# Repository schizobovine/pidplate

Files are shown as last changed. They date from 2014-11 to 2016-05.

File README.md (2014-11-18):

pidplate
========

Arduino-ish PID temperature controller for a hotplate based solder reflow-ing thingy.

hardware - Contains the Eagle schematic and board layout
firmware - Arduino sketch & makefile to build code to run it

Bill of materials still TODO, as I haven't really finalized each part, but know
the footprints for each and want to get the board to the fab before I grow old.

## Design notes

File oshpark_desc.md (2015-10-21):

PID temperature controller shield for reading in thermocouple data and using the results to control a SSR. Based on MAX 31855 thermocouple amplifier. Has a [Newport PCC-SMP-K mini thermocouple connector](http://www.newark.com/newport-electronics/pcc-smp-k/thermocouple-connector-type-k/dp/01H0905), JST XH-4 connector to the SSR/PSU assembly, and a header for the [Adafruit 128x32 I2C OLED Display](https://www.adafruit.com/products/931).

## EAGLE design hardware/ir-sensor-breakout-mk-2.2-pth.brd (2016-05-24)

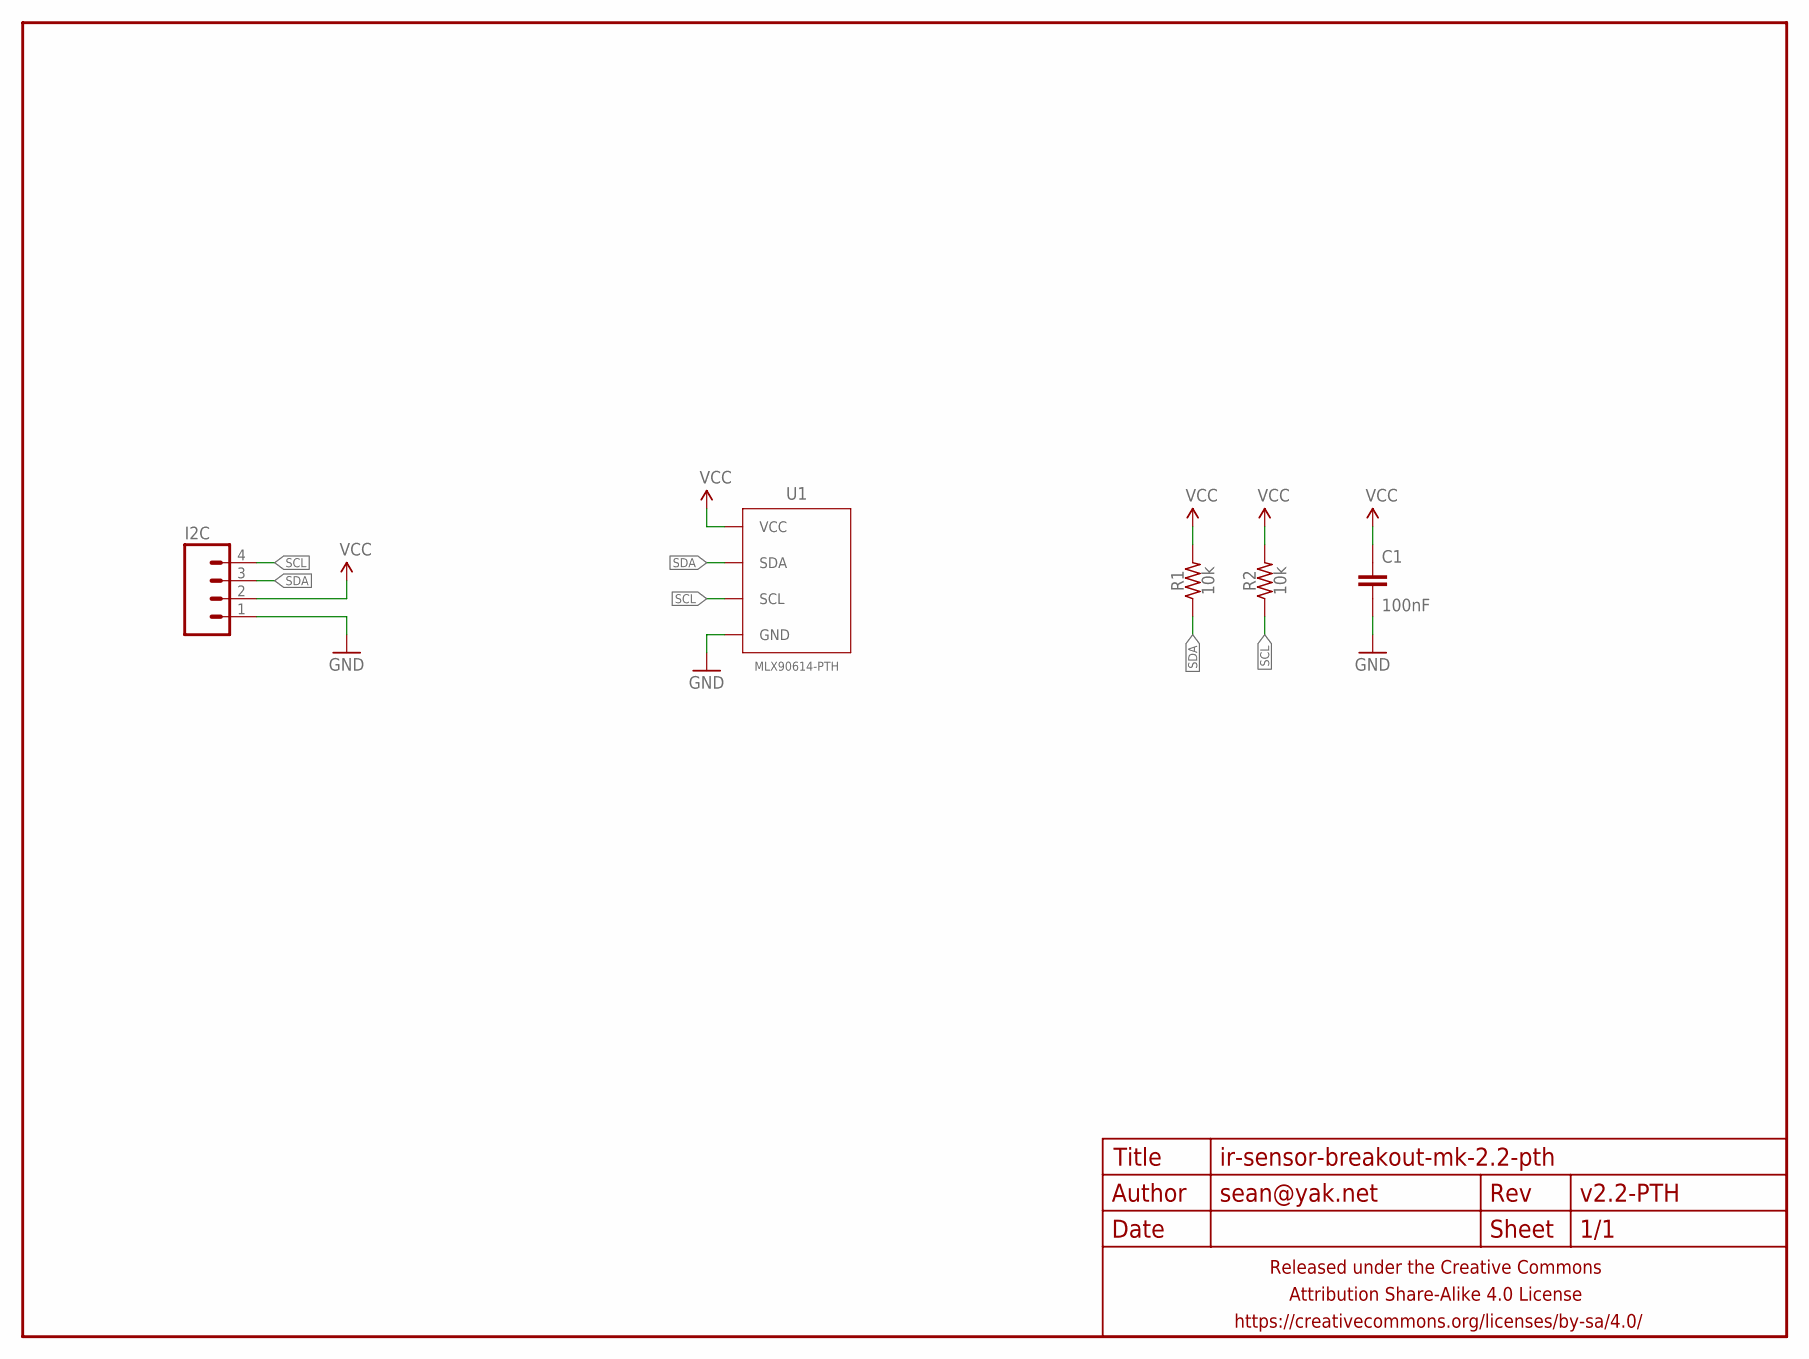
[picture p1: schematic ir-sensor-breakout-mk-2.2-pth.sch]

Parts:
C1: 100nF; C025-024X044
FRAME1: FRAME-LETTERNO_PACKAGE; DUMMY
I2C: M04JST-PTH-VERT; JST-4-PH-VERT-PTH
R1, R2: 10k; RESISTOR-AXIAL-PTH-6.35MM
U1: MLX90614-PTH; TO-39-4

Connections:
GND: C1.2, I2C.1, U1.4 (GND)
SCL: I2C.4, R2.P$1 (1), U1.1 (SCL)
SDA: I2C.3, R1.P$1 (1), U1.2 (SDA)
VCC: C1.1, I2C.2, R1.P$2 (2), R2.P$2 (2), U1.3 (VCC)

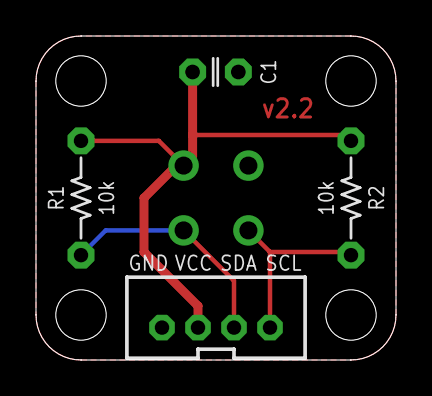
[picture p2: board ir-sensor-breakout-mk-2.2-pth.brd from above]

Board: 2 copper layers, 20.0 x 18.0 mm, 6 parts (1 on the bottom side), 4 nets.

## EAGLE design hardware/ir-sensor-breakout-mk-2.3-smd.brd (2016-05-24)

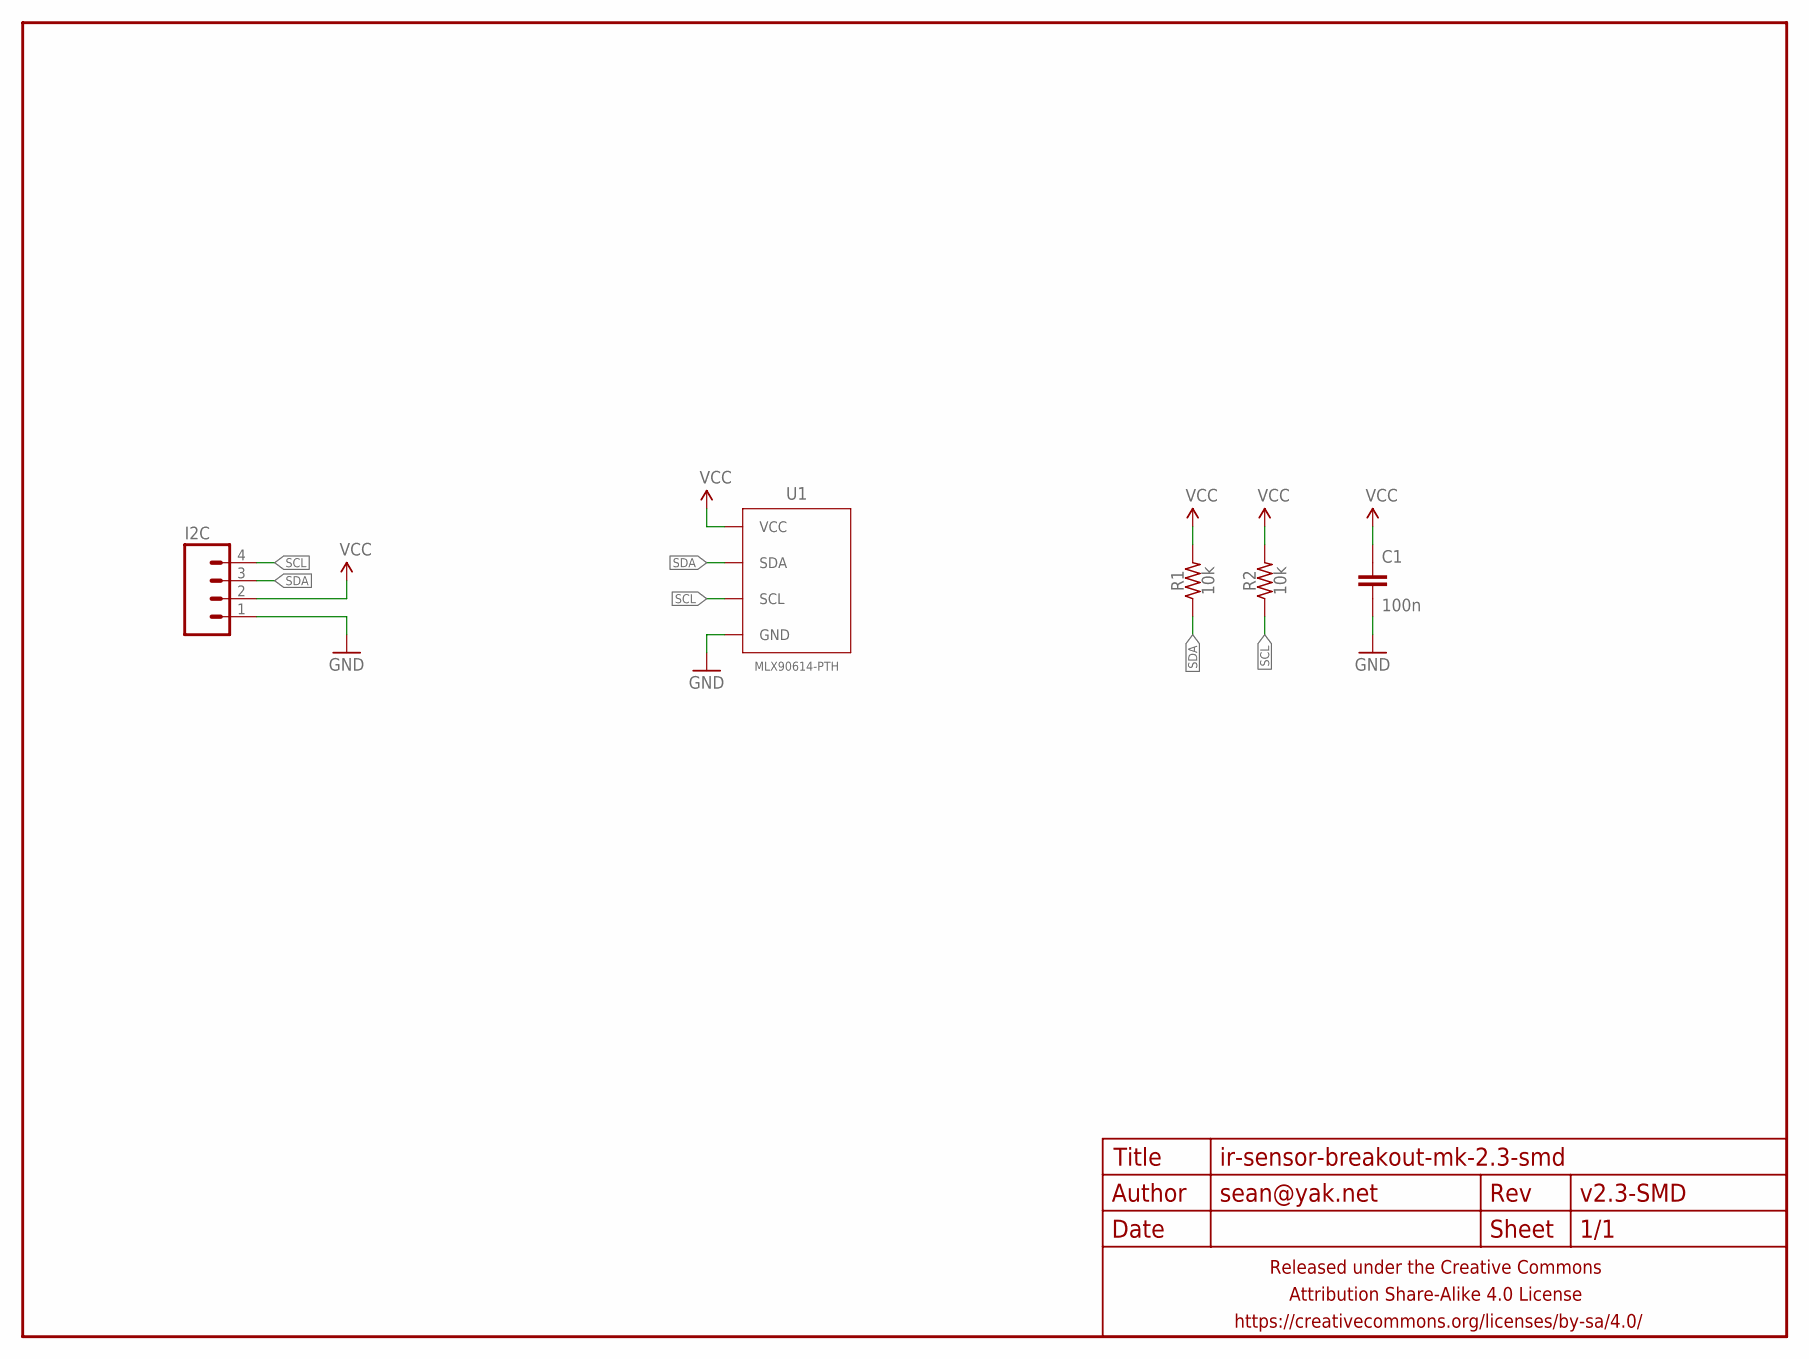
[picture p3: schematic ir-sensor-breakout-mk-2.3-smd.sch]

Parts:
C1: 100n; C0805
FRAME1: FRAME-LETTERNO_PACKAGE; DUMMY
I2C: M04JST-PTH-VERT; JST-4-PH-VERT-PTH
R1, R2: 10k; R0805
U1: MLX90614-PTH; TO-39-4

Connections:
GND: C1.2, I2C.1, U1.4 (GND)
SCL: I2C.4, R2.1, U1.1 (SCL)
SDA: I2C.3, R1.1, U1.2 (SDA)
VCC: C1.1, I2C.2, R1.2, R2.2, U1.3 (VCC)

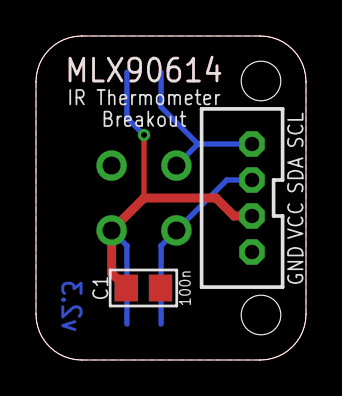
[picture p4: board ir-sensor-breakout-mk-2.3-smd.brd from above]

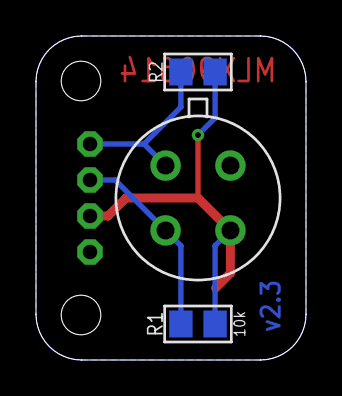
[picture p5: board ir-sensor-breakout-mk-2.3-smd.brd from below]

Board: 2 copper layers, 15.0 x 18.0 mm, 6 parts (3 on the bottom side), 4 nets.

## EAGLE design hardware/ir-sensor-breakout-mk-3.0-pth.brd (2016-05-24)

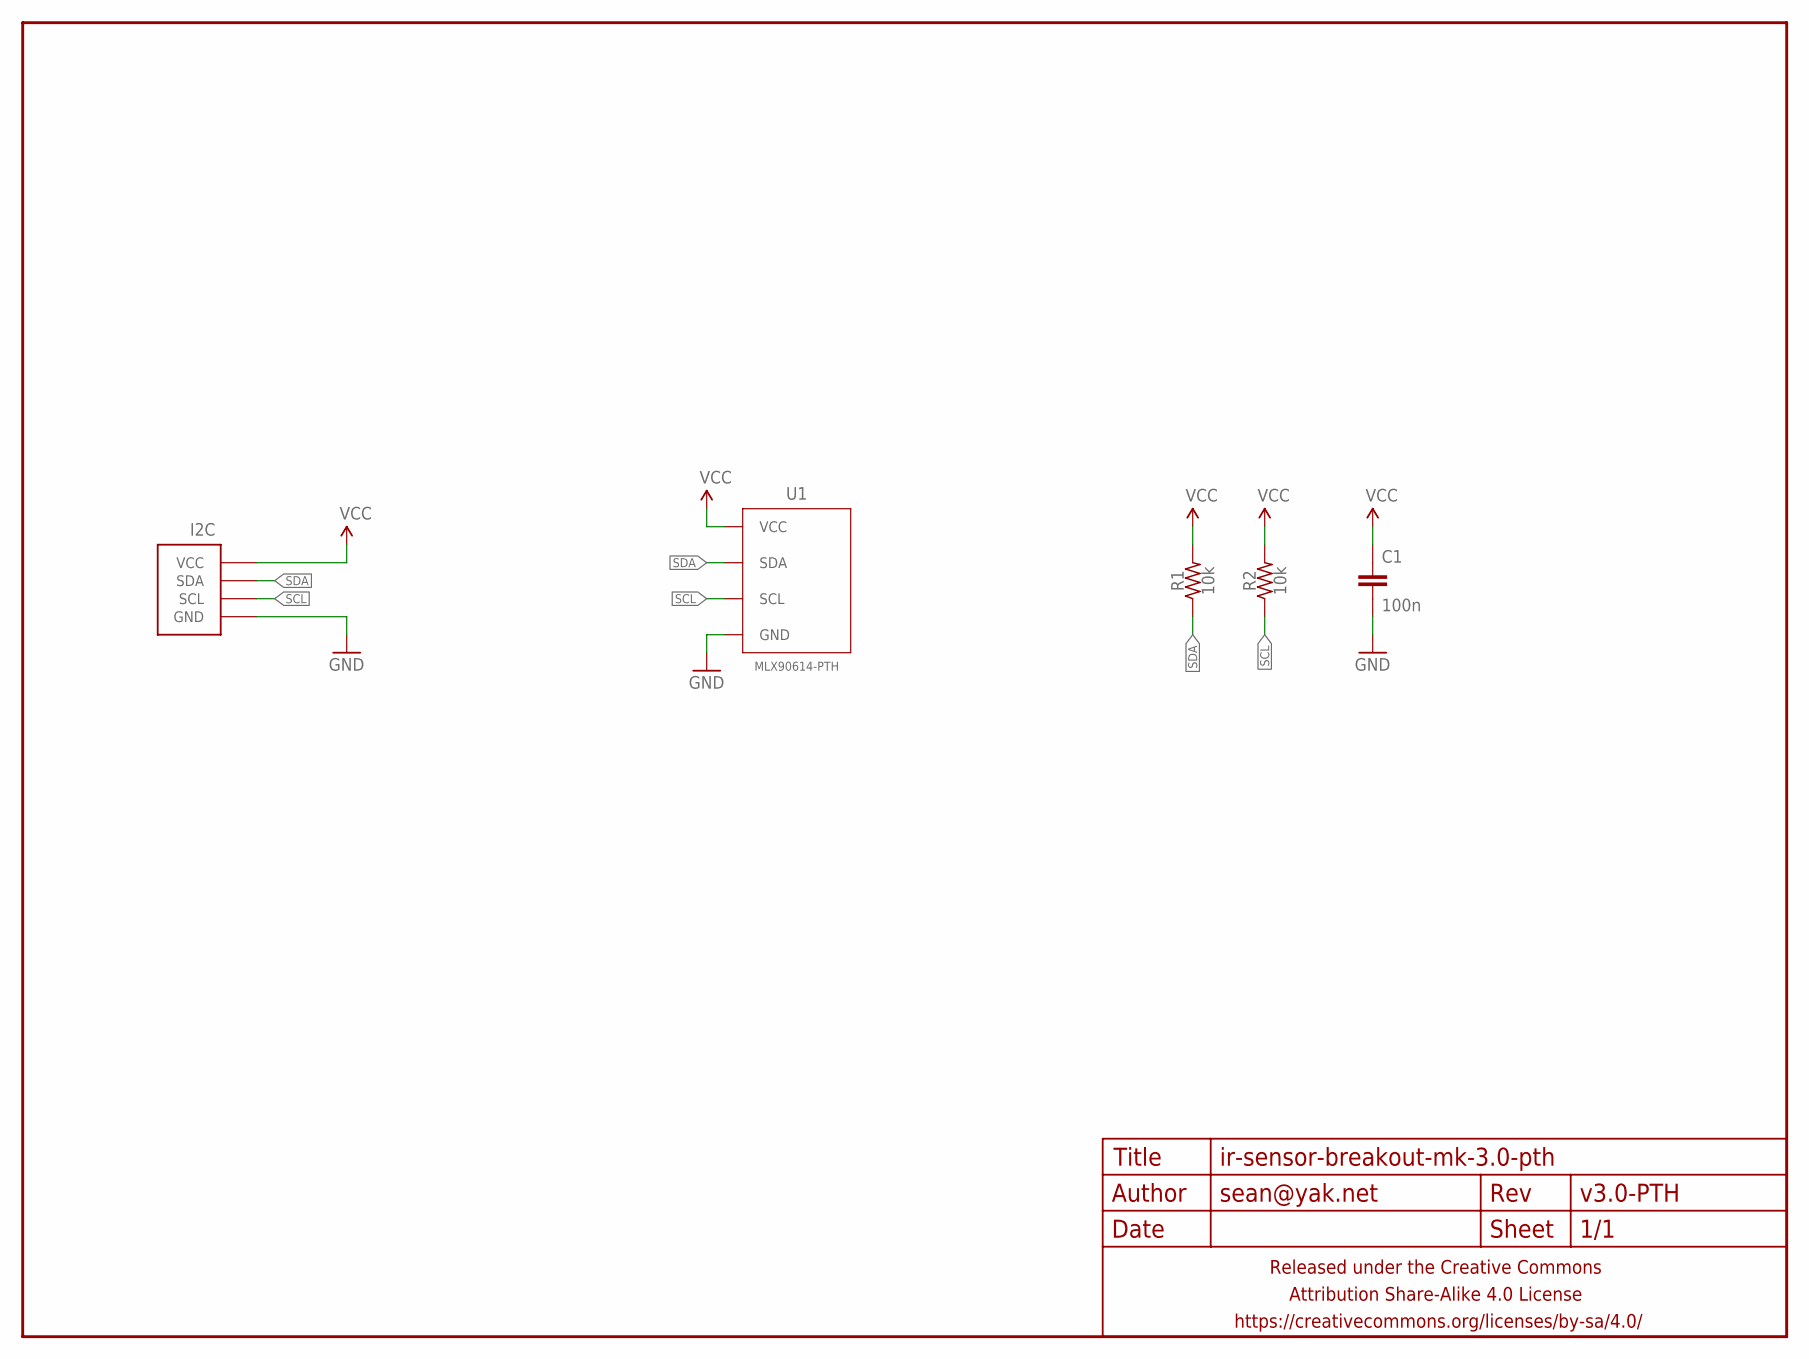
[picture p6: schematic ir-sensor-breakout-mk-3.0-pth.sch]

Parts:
C1: 100n; C025-024X044
FRAME1: FRAME-LETTERNO_PACKAGE; DUMMY
I2C: M04-I2CPTH-0.1IN-CENTERED-FLIPPED; 1X04-PTH-VERT-I2C-CENTERED-FLIPPED
R1, R2: 10k; RESISTOR-AXIAL-PTH-5.08MM
U1: MLX90614-PTH; TO-39-4

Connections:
GND: C1.2, I2C.GND, U1.4 (GND)
SCL: I2C.SCL, R2.P$1 (1), U1.1 (SCL)
SDA: I2C.SDA, R1.P$1 (1), U1.2 (SDA)
VCC: C1.1, I2C.VCC, R1.P$2 (2), R2.P$2 (2), U1.3 (VCC)

Board: 2 copper layers, 6 parts (1 on the bottom side), 4 nets, no tracks yet.

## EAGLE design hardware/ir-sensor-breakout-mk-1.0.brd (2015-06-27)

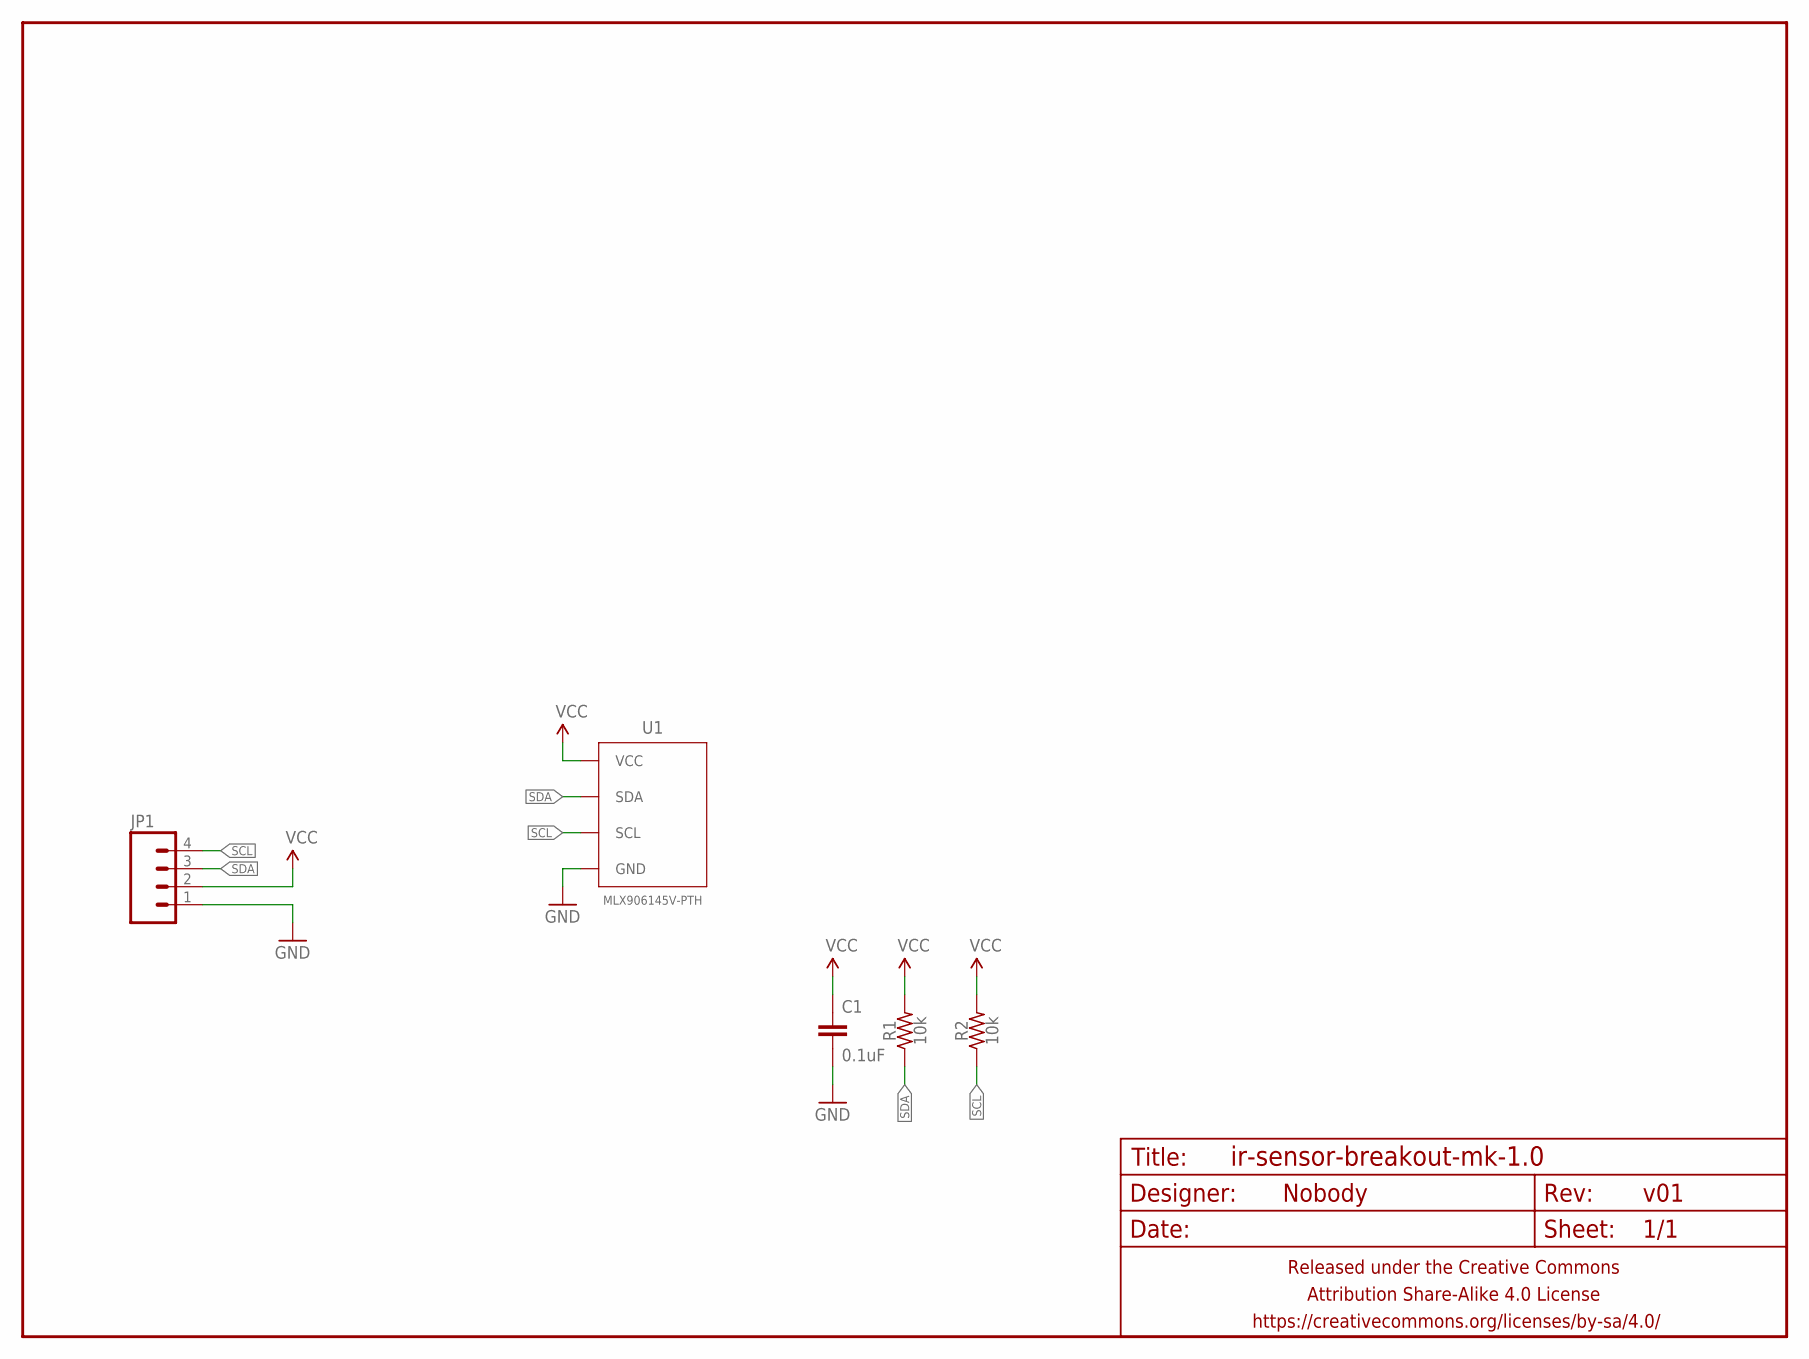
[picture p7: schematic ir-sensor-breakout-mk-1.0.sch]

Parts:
C1: 0.1uF; C025-024X044
FRAME1: FRAME-LETTERNO_PACKAGE; DUMMY
JP1: M04JST-PTH; JST-4-PH-RA-PTH
R1, R2: 10k; RESISTOR-AXIAL-PTH-7.62MM
U1: MLX906145V-PTH; TO-39-4

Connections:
GND: C1.2, JP1.1, U1.4 (GND)
SCL: JP1.4, R2.P$1 (1), U1.1 (SCL)
SDA: JP1.3, R1.P$1 (1), U1.2 (SDA)
VCC: C1.1, JP1.2, R1.P$2 (2), R2.P$2 (2), U1.3 (VCC)

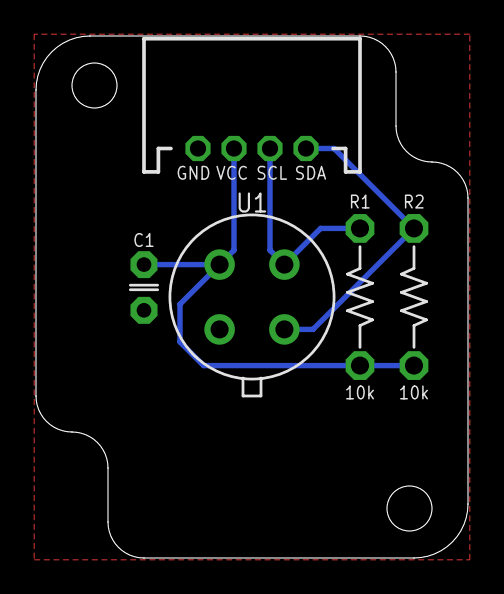
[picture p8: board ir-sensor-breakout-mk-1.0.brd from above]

Board: 2 copper layers, 24.0 x 29.0 mm, 6 parts (0 on the bottom side), 4 nets.

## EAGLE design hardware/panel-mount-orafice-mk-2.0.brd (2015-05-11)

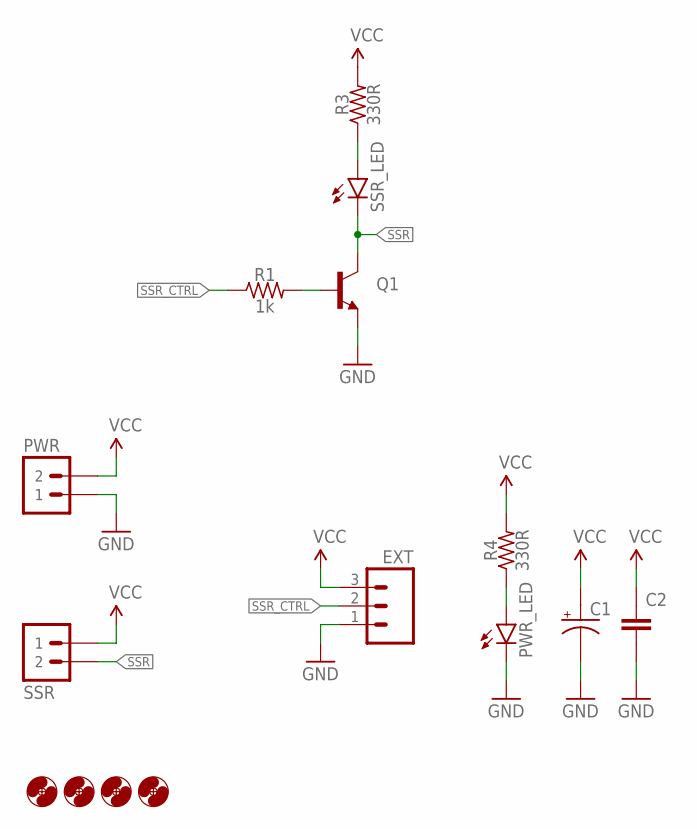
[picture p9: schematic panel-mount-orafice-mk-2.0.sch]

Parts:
C1: CAPACITOR-POLARIZEDE3.5-8; E3,5-8
C2: CAPACITOR-CERAMIC025-024X044; C025-024X044
EXT: M03JST-XH-RA-PTH; JST-3-XH-RA-PTH
H1, H2, H3, H4: HOLE#2; HOLE-#2
PWR: M02JST-PTH-VERT; JST-2-PH-VERT-PTH
PWR_LED: LED3MM
Q1: TRANSISTOR_NPNTO-92-AMMO-EBC; TO-92-AMMO
R1: 1k; RESISTOR-AXIAL-PTH-6.35MM
R3, R4: 330R; RESISTOR-AXIAL-PTH-6.35MM
SSR: M02JST-PTH-VERT; JST-2-PH-VERT-PTH
SSR_LED: LED3MM

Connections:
GND: C1.-, C2.2, EXT.1, PWR.1, PWR_LED.K (C), Q1.1 (E)
unnamed: Q1.2 (B), R1.P$2 (2)
unnamed: R3.P$1 (1), SSR_LED.A
unnamed: PWR_LED.A, R4.P$1 (1)
SSR: Q1.3 (C), SSR.2, SSR_LED.K (C)
SSR_CTRL: EXT.2, R1.P$1 (1)
VCC: C1.+, C2.1, EXT.3, PWR.2, R3.P$2 (2), R4.P$2 (2), SSR.1

Board: 2 copper layers, 15 parts (0 on the bottom side), 7 nets, no tracks yet.

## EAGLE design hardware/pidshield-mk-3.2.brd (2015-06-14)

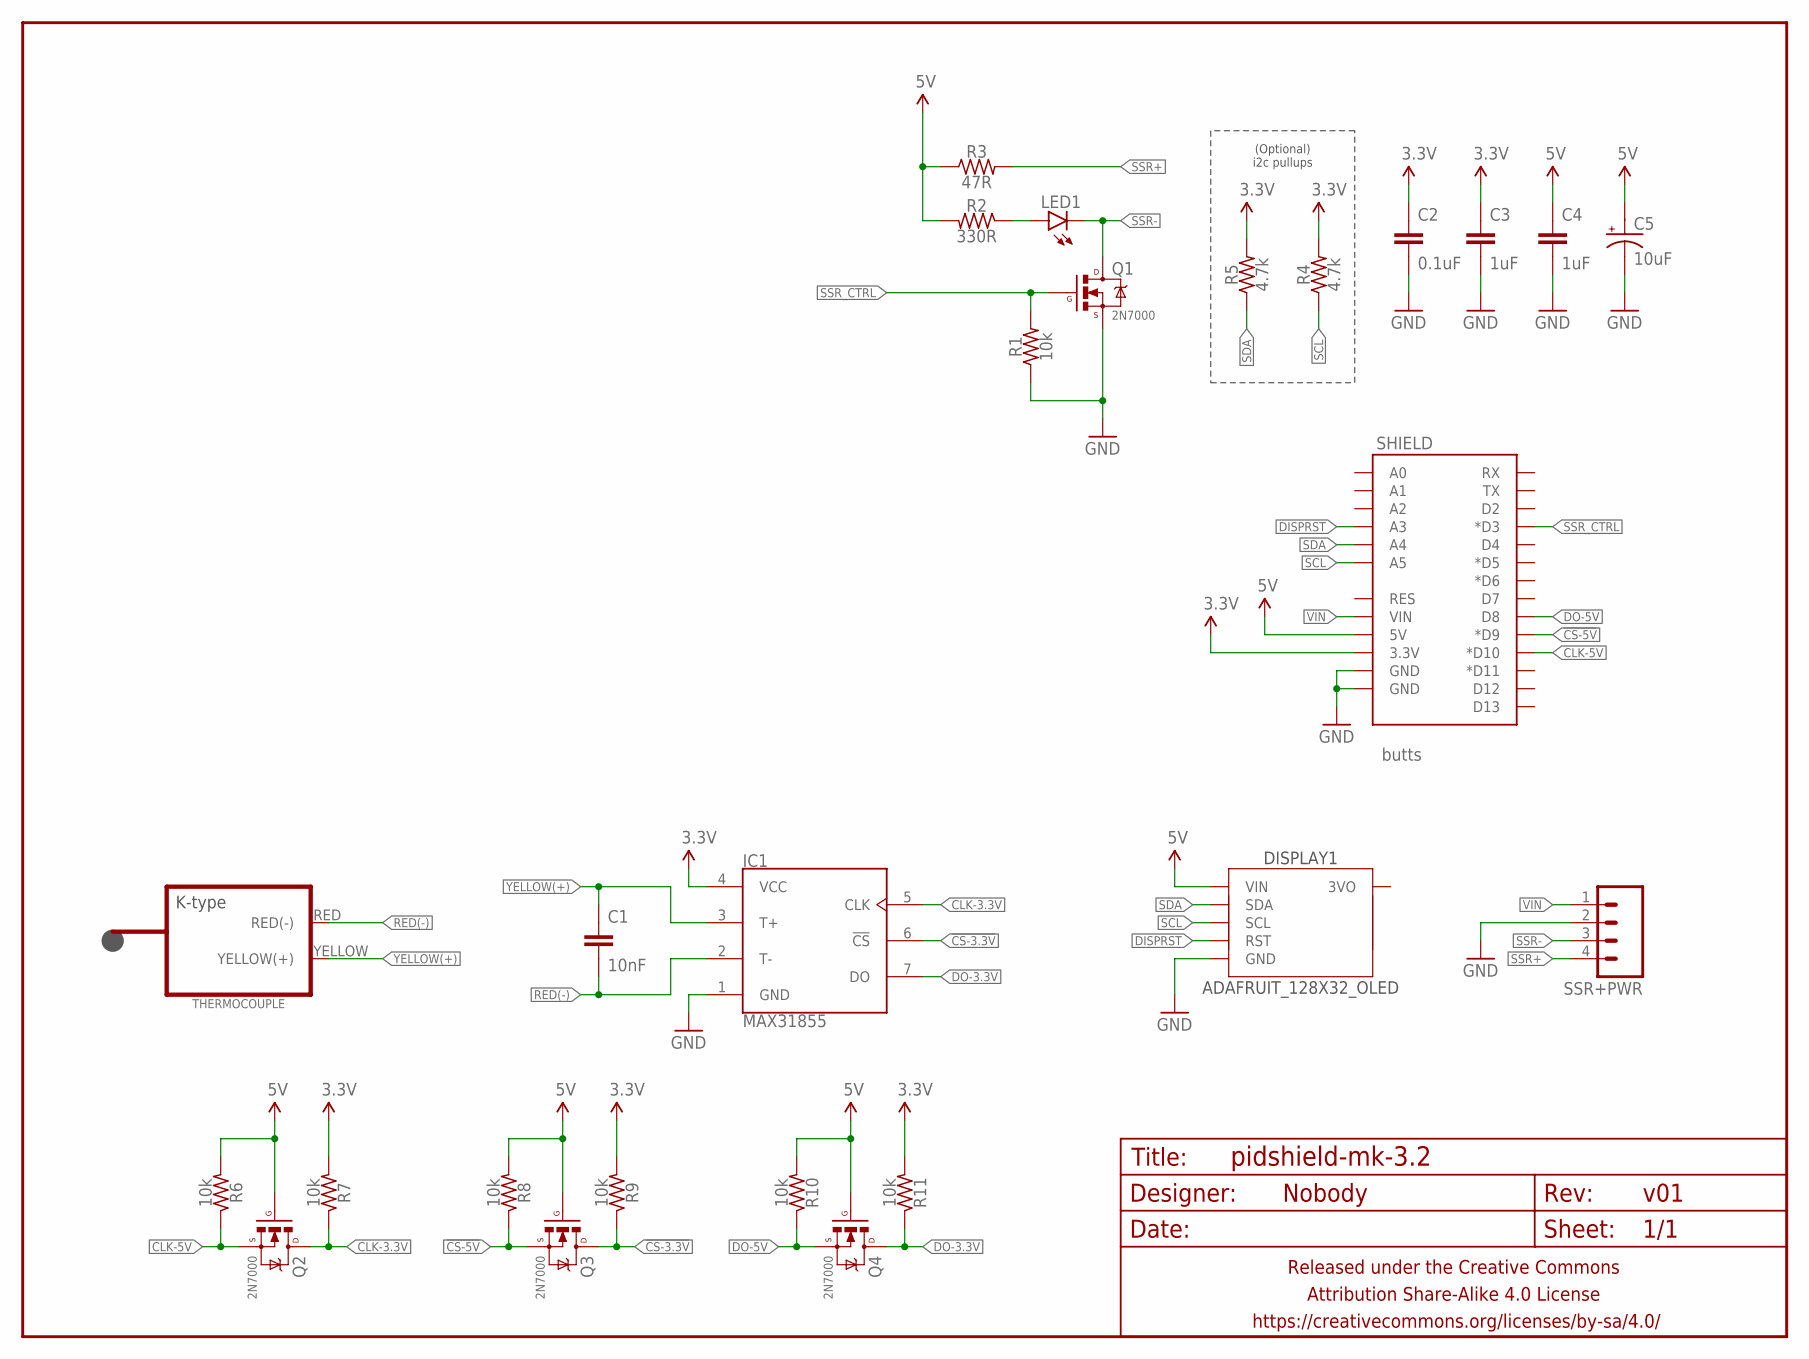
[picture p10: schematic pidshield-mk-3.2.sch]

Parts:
C1: 10nF; C0805
C2: 0.1uF; C025-024X044
C3, C4: 1uF; C025-024X044
C5: 10uF; E2,5-6
DISPLAY1: ADAFRUIT_128X32_OLED; ADAFRUIT_128X32_OLED_I2C_CLOSER_NOTITLE
FRAME1: FRAME-LETTERNO_PACKAGE; DUMMY
IC1: MAX31855; SOIC127P600X175-8N
LED1: LED3MM-LESS; LED3MM-LESSSILK
Q1, Q2, Q3, Q4: 2N7000; TO-92-AMMO
R1, R6, R7, R8, R9, R10, R11: 10k; RESISTOR-AXIAL-PTH-7.62MM
R2: 330R; RESISTOR-AXIAL-PTH-7.62MM
R3: 47R; RESISTOR-AXIAL-PTH-7.62MM
R4, R5: 4.7k; RESISTOR-AXIAL-PTH-7.62MM
SHIELD: butts; ARDUINO_SHIELD_SMALLER_NEKKID
SSR+PWR: M04JST_XH_RA; JST-4-XH-RA-PTH
THERMOCOUPLE: THERMOCOUPLE-CONNECTORMINI-PCB; PCC-SMP

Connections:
3.3V: C2.1, C3.1, IC1.4 (VCC), R4.P$2 (2), R5.P$2 (2), R7.P$2 (2), R9.P$2 (2), R11.P$2 (2), SHIELD.3.3V
5V: C4.1, C5.+, DISPLAY1.VIN, Q2.2 (G), Q3.2 (G), Q4.2 (G), R2.P$2 (2), R3.P$1 (1), R6.P$2 (2), R8.P$2 (2), R10.P$2 (2), SHIELD.5V
!CS-3.3V: IC1.6 (!CS), Q3.3 (D), R9.P$1 (1)
!CS-5V: Q3.1 (S), R8.P$1 (1), SHIELD.D9 (*D9)
CLK-3.3V: IC1.5 (CLK), Q2.3 (D), R7.P$1 (1)
CLK-5V: Q2.1 (S), R6.P$1 (1), SHIELD.D10 (*D10)
DISPRST: DISPLAY1.RST, SHIELD.A3
DO-3.3V: IC1.7 (DO), Q4.3 (D), R11.P$1 (1)
DO-5V: Q4.1 (S), R10.P$1 (1), SHIELD.D8
GND: C2.2, C3.2, C4.2, C5.-, DISPLAY1.GND, IC1.1 (GND), Q1.1 (S), R1.P$1 (1), SHIELD.GND@0 (GND), SHIELD.GND@1 (GND), SSR+PWR.2
unnamed: LED1.A, R2.P$1 (1)
RED(-): C1.2, IC1.2 (T-), THERMOCOUPLE.RED (RED(-))
SCL: DISPLAY1.SCL, R4.P$1 (1), SHIELD.A5
SDA: DISPLAY1.SDA, R5.P$1 (1), SHIELD.A4
SSR+: R3.P$2 (2), SSR+PWR.4
SSR-: LED1.K (C), Q1.3 (D), SSR+PWR.3
SSR_CTRL: Q1.2 (G), R1.P$2 (2), SHIELD.D3 (*D3)
VIN: SHIELD.VIN, SSR+PWR.1
YELLOW(+): C1.1, IC1.3 (T+), THERMOCOUPLE.YELLOW (YELLOW(+))

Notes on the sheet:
(Optional) i2c pullups

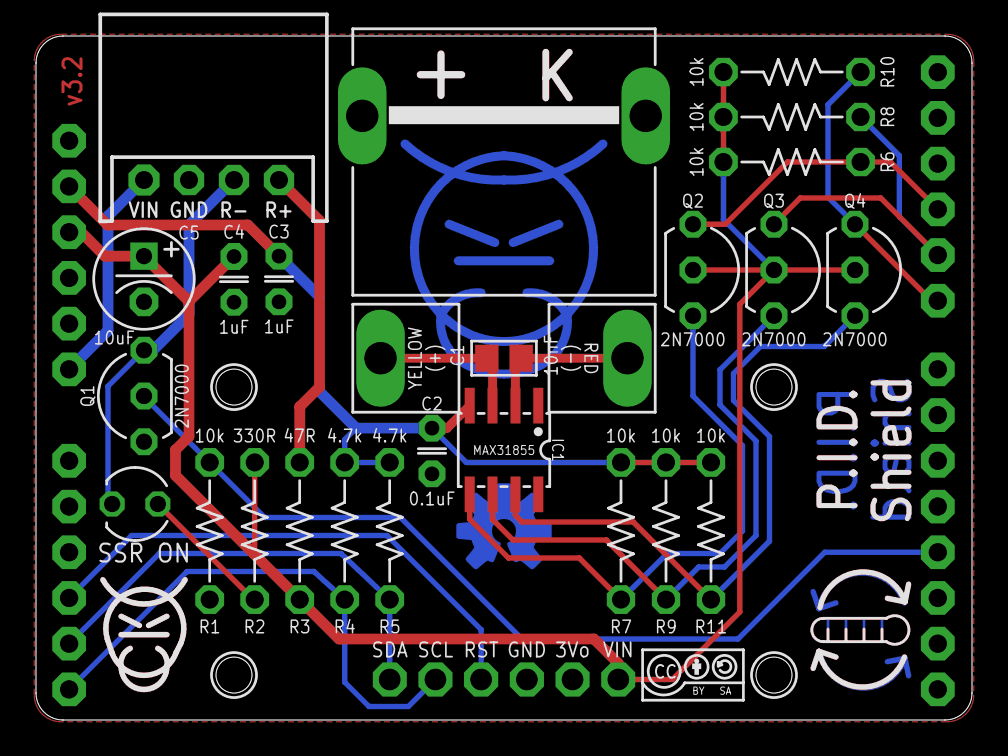
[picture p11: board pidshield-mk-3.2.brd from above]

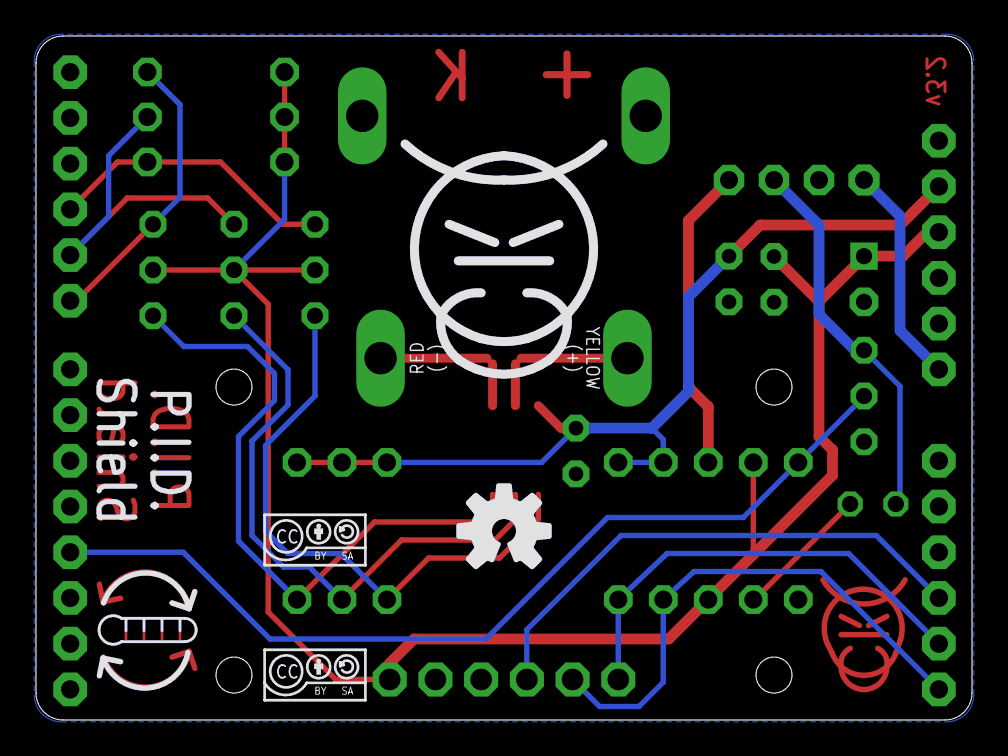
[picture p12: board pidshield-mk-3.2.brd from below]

Board: 2 copper layers, 52.0 x 38.0 mm, 35 parts (4 on the bottom side), 19 nets.

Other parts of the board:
U$1: COW_METAL
U$2, U$4, U$5: CC-BY-SA-4.0-NO-URL
U$3, U$6: FEEDBACK3
U$7: OSHWLOGO_BOT_0.2_A
U$8: COW_SMALL_METAL_NOTEXT

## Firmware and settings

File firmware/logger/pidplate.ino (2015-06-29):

/*
 * pidplate.ino
 *
 * Test sketch to build my very own PID (Psomething Interval(?) Derivative)
 * controller using a fucking ridiculous 40A solid state relay. (Seriously,
 * this thing is fucking overkill like WHOA.)
 *
 */

#include <stdlib.h>
#include <stdio.h>
#include <string.h>
#include <math.h>
#include <avr/io.h>
#include <avr/pgmspace.h>

#include <Arduino.h>
#include <Wire.h>

#include <Adafruit_GFX.h>
#include <Adafruit_SSD1306.h>
#include <Adafruit_MAX31855.h>

#include "usec.h"
#include "pidplate.h"

/***********************************************************************
 * Globals
 ***********************************************************************/

// THERMOCOUPLE AMP
Adafruit_MAX31855 tc(THERMO_CLK, THERMO_CS, THERMO_DO);

// DISPLAY
Adafruit_SSD1306 display(DISPLAY_RST);

// UART data speed
const int SERIAL_BAUD = 9600;

// Milliseconds since start of run
usec time_start = 0;

// Milliseconds since last serial logging
usec time_last_dump = 0;

// Last temperature reading
double last_temp = 0.0;

// SSR level
double ssrPWM = 0.0;

/***********************************************************************
 * "Halping"
 ***********************************************************************/

double readThermocouple() {
  double t = tc.readCelsius();

  // Only set the current temp if it's sane to prevent the PID controller from
  // going haywire if the TC fucks up
  if (t != NAN && t > -100 && t < 3000) {
    return t;
  } else {
    //Return last reading so shit doesn't bounce around like a Jack Russell
    //fucking terrier
    return last_temp; 
  }
}

//
// Display current temp, setpoint temp, SSR level, and time since boot
//
void refreshDisplay(usec now) {

  // Format strings, stored in program memory to avoid wasting precious
  // precious RAMz.
  PGM_P DISP_FMT = PSTR(
         "Temp %#5.1f\367C"
    "\n" "SetP     OFF"
    "\n" "PWM      OFF"
    "\n" "  %2.2u:%2.2u:%2.2u"
  );

  // String-ify display data in a C-ish style way since the Arduino libs don't
  // really give us any way to handle this well (which is annoying). Note that
  // special linker flags are required to bring in the full vprintf
  // implementation for floating point number. Check the Makefile for the
  // voodoo.
  char buff[21*4+1];
  int h = now / 1000 / 60 / 60 % 100;
  int m = now / 1000 / 60 % 60;
  int s = now / 1000 % 60;
  snprintf_P(buff, sizeof(buff), DISP_FMT, last_temp, h, m, s);
  buff[sizeof(buff)-1] = '\0';

  // Actually shart chars to display
  display.clearDisplay();
  display.setCursor(0, 0);
  display.println(buff);
  display.display();

}

//
// Output current time, temp, and SSR level to serial port
//
void outputData(usec now) {
  Serial.print(now, DEC);
  Serial.print(", ");
  Serial.print(last_temp, DEC);
  Serial.print(", ");
  Serial.print(ssrPWM, DEC);
  Serial.print("\r\n");
}

/***********************************************************************
 * setup() - this is done once
 ***********************************************************************/

void setup() {

  // Initialize SSR to default off
  pinMode(SSR, OUTPUT);
  analogWrite(SSR, 0);

  // Boot up display
  Wire.begin();
  display.begin(DISPLAY_MODE, DISPLAY_ADDR);
  display.clearDisplay();
  display.setTextColor(DISPLAY_COLOR);
  display.setTextSize(DISPLAY_TEXTSIZE);
  display.println("");
  display.println("      PID Plate");
  display.println("        Hello!");
  display.display();

  // Initialize serial port after waiting a sec
  Serial.begin(SERIAL_BAUD);
  while (!Serial)
    ;

  // Wait for someone to pick up the phone
  while (!Serial.find(TOKEN_START))
    ;

  // Begin data dump
  time_start = millis();
  time_last_dump = time_start - LOG_INTERVAL_MS;
  Serial.println();
  Serial.println("time_ms,temp_c,pwm");

}

uint8_t repeated_reading = 0;

/***********************************************************************
 * loop() - this is done all the time (like your mom)
 ***********************************************************************/

void loop() {
  
  // Get reading from thermocouple
  last_temp = readThermocouple();

  // Get ticks since startup
  uint32_t now = millis();

  // Figure out if SSR needs to be ON or OFF
  if (USEC_DIFF(now, time_start) <= RUN_TIME) {
    if (ssrPWM <= 0) {
      ssrPWM = RUN_LEVEL;
      analogWrite(SSR, ssrPWM);
    }
  } else {
    if (ssrPWM >= 0) {
      ssrPWM = 0;
      analogWrite(SSR, ssrPWM);
    }
  }

  // Update display
  refreshDisplay(now);

  // If it's time, dump serial data
  if (USEC_DIFF(now, time_last_dump) >= LOG_INTERVAL_MS) {
    outputData(now);
  }

}

// vi: syntax=arduino sw=2 ts=2

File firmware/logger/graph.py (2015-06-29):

#!/usr/bin/env python

import sys
import wx

import matplotlib
from matplotlib.figure import Figure
from matplotlib.backends import backend_wxagg as backend_wxagg 
from backend_wxagg import FigureCanvasWxAgg as FigCanvas
from backend_wxagg import NavigationToolbar2WxAgg as NavigationToolbar

import pylab

matplotlib.use('WXAgg')

REFRESH_INTERVAL_MS = 100

class GraphFrame(wx.Frame):
    '''Window for graphing stuff.'''

    def __init__(self):
        super(GraphFrame, self).__init__(None, -1, 'pidplate')

        self.data = []
        self.paused = False

        self.create_menu()
        self.create_status_bar()
        self.create_main_panel()

        self.redraw_timer = wx.Timer(self)
        self.Bind(wx.EVT_TIMER, self.on_redraw_timer, self.redraw_timer)
        self.redraw_timer.Start(REFRESH_INTERVAL_MS)

    def init_plot(self):
        # TODO wtf with all these magic numbers?
        self.dpi = 100
        self.fig = Figure((3.0, 3.0), dpi=self.dpi)
        self.axes = self.fig.add_subplot(111)
        self.axes.set_axis_bgcolor('black')
        self.axes.set_title('butts', size=12)

        pylab.setp(self.axes.get_xticklabels(), fontsize=8)
        pylab.setp(self.axes.get_yticklabels(), fontsize=8)

    def create_menu(self):

        self.menubar = wx.MenuBar()
        
        menu_file = wx.Menu()
        m_expt = menu_file.Append(-1, "&Save plot\tCtrl-S", "Save plot to file")
        self.Bind(wx.EVT_MENU, self.on_save_plot, m_expt)

        menu_file.AppendSeparator()

        m_exit = menu_file.Append(-1, "E&xit\tCtrl-X", "Exit")
        self.Bind(wx.EVT_MENU, self.on_exit, m_exit)
                
        self.menubar.Append(menu_file, "&File")
        self.SetMenuBar(self.menubar)

    def create_status_bar(self):
        self.statusbar = self.CreateStatusBar()

    def create_main_panel(self):

        self.panel = wx.Panel(self)
        self.init_plot()

        #self.xmin_control = BoundControlBox(self.panel, -1, "X min", 0)
        #self.xmax_control = BoundControlBox(self.panel, -1, "X max", 50)
        #self.ymin_control = BoundControlBox(self.panel, -1, "X min", 0)
        #self.ymax_control = BoundControlBox(self.panel, -1, "X max", 100)

        self.pause_button = wx.Button(self.panel, -1, "Pause")
        self.Bind(wx.EVT_BUTTON, self.on_pause_button, self.pause_button)
        self.Bind(wx.EVT_UPDATE_UI, self.on_update_pause_button, self.pause_button)

        self.cb_grid = wx.CheckBox(self.panel, -1, "Show Grid", style=wx.ALIGN_RIGHT)
        self.Bind(wx.EVT_CHECKBOX, self.on_cb_grid, self.cb_grid)
        self.cb_grid.SetValue(True)

        self.cb_xlab = wx.CheckBox(self.panel, -1, 
            "Show X labels",
            style=wx.ALIGN_RIGHT)
        self.Bind(wx.EVT_CHECKBOX, self.on_cb_xlab, self.cb_xlab)        
        self.cb_xlab.SetValue(True)

        self.hbox1 = wx.BoxSizer(wx.HORIZONTAL)
        self.hbox1.Add(self.pause_button, border=5, flag=wx.ALL | wx.ALIGN_CENTER_VERTICAL)
        self.hbox1.AddSpacer(20)
        self.hbox1.Add(self.cb_grid, border=5, flag=wx.ALL | wx.ALIGN_CENTER_VERTICAL)
        self.hbox1.AddSpacer(10)
        self.hbox1.Add(self.cb_xlab, border=5, flag=wx.ALL | wx.ALIGN_CENTER_VERTICAL)
        
        #self.hbox2 = wx.BoxSizer(wx.HORIZONTAL)
        #self.hbox2.Add(self.xmin_control, border=5, flag=wx.ALL)
        #self.hbox2.Add(self.xmax_control, border=5, flag=wx.ALL)
        #self.hbox2.AddSpacer(24)
        #self.hbox2.Add(self.ymin_control, border=5, flag=wx.ALL)
        #self.hbox2.Add(self.ymax_control, border=5, flag=wx.ALL)
        
        self.vbox = wx.BoxSizer(wx.VERTICAL)
        self.vbox.Add(self.canvas, 1, flag=wx.LEFT | wx.TOP | wx.GROW)        
        self.vbox.Add(self.hbox1, 0, flag=wx.ALIGN_LEFT | wx.TOP)
        #self.vbox.Add(self.hbox2, 0, flag=wx.ALIGN_LEFT | wx.TOP)
        
        self.panel.SetSizer(self.vbox)
        self.vbox.Fit(self)

    def on_pause_button(self, event):
        self.paused = not self.paused
    
    def on_update_pause_button(self, event):
        label = "Resume" if self.paused else "Pause"
        self.pause_button.SetLabel(label)
    
    def on_cb_grid(self, event):
        self.draw_plot()
    
    def on_cb_xlab(self, event):
        self.draw_plot()

    def on_redraw_timer(self, event):

        # if paused do not add data, but still redraw the plot
        # (to respond to scale modifications, grid change, etc.)

        #if not self.paused:
        #    self.data.append(self.datagen.next())
        
        self.draw_plot()
    
    def on_exit(self, event):
        self.Destroy()

    def flash_status_message(self, msg, flash_len_ms=1500):
        self.statusbar.SetStatusText(msg)
        self.timeroff = wx.Timer(self)
        self.Bind(
            wx.EVT_TIMER, 
            self.on_flash_status_off, 
            self.timeroff)
        self.timeroff.Start(flash_len_ms, oneShot=True)
    
    def on_flash_status_off(self, event):
        self.statusbar.SetStatusText('')


if __name__ == '__main__':
    app = wx.PySimpleApp()
    app.frame = GraphFrame()
    app.frame.Show()
    app.MainLoop()

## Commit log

2014-11-18 Finally getting this bastard into source control. Bad programmer, I know. :P
    [pidplate-mk-1.brd, pidplate-mk-1.sch]
2014-12-11 misc changes upon receiving boards, and some work maybe on the firmware
    [pidplate-mk-2.brd, pidplate-mk-2.sch]
2014-12-12 revision dos will use 3.3V power to make life easier
    [pidplate-mk-2.1.brd, pidplate-mk-2.1.sch]
2014-12-12 now 50x50mm, reduced components, relatively happy with layout
    [pidplate-mk-2.1.brd, pidplate-mk-2.1.sch]
2014-12-14 mini mini mini
    [pidplate-mk-2.1.brd, pidplate-mk-2.1.sch]
2014-12-15 more tweaks to standalone; new shield-based version
    [pidplate-mk-2.1.brd, pidshield-mk-1.brd, pidshield-mk-1.sch]
2014-12-15 think i've got the layout how i want it
    [pidshield-mk-1.brd, pidshield-mk-1.sch]
2014-12-21 new shield for 3.3V boards only, so no need for a crapload of MOSFETs
    [pidshield-mk-2.brd, pidshield-mk-2.sch]
2014-12-28 in progress commit
    [pidshield-mk-2.brd]
2014-12-28 switchover to using 7seg display b/c fuck LCDs
2015-05-11 complete relayout of PTH shield to use a tiny OLED display from Adafruit
    [pidshield-mk-2.1.brd, pidshield-mk-2.1.sch, pidshield-mk-3.0.brd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]
2015-05-11 originally to mount a connector to the outside of the case
    [panel-mount-orafice-mk-1.brd, panel-mount-orafice-mk-1.sch]
2015-05-11 breakout for Melexis IR temp sensor for future version
    [ir-sensor-breakout.brd, ir-sensor-breakout.sch]
2015-06-14 new revision swap BJT for FET and add appropriate pullup
    [pidshield-mk-3.2.brd, pidshield-mk-3.2.sch]
2015-06-22 not sure what i was going to do with this
    [panel-mount-orafice-mk-2.0.brd, panel-mount-orafice-mk-2.0.sch]
2015-06-22 changes to make controller work both in arduino land and on the Linux CLI
2015-06-27 twiddling around with IR sensor breakouts
    [ir-sensor-breakout-drill-template-mk-1.0.brd, ir-sensor-breakout-drill-template-mk-1.0.sch, ir-sensor-breakout-mk-1.0.brd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]
2015-06-27 data logger sketch for plate
2015-06-28 fiddling with the pth breakout
    [ir-sensor-breakout-mk-2.0.brd, ir-sensor-breakout-mk-2.0.sch]
2015-06-29 graphing sucks. why didn't i use a spreadsheet?
    [graph.py, pidplate.ino]
2015-06-29 removing some dead-ends/boards not going to be fabbed
    [ir-sensor-breakout-drill-template-mk-1.0.brd, ir-sensor-breakout-drill-template-mk-1.0.sch, ir-sensor-breakout.brd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]
2016-05-23 new IR thermometer breakouts
    [ir-sensor-breakout-mk-2.2-pth.brd, ir-sensor-breakout-mk-2.2-pth.sch, ir-sensor-breakout-mk-2.2-smd.brd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]
2016-05-24 tinier version
    [ir-sensor-breakout-mk-3.1.brd, ir-sensor-breakout-mk-3.1.sch]

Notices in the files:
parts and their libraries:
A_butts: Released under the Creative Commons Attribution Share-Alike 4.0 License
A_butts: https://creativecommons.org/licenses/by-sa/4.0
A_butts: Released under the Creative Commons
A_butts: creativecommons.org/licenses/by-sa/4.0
